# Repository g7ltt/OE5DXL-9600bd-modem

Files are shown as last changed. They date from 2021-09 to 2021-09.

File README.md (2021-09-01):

# OE5DXL-9600bd-modem

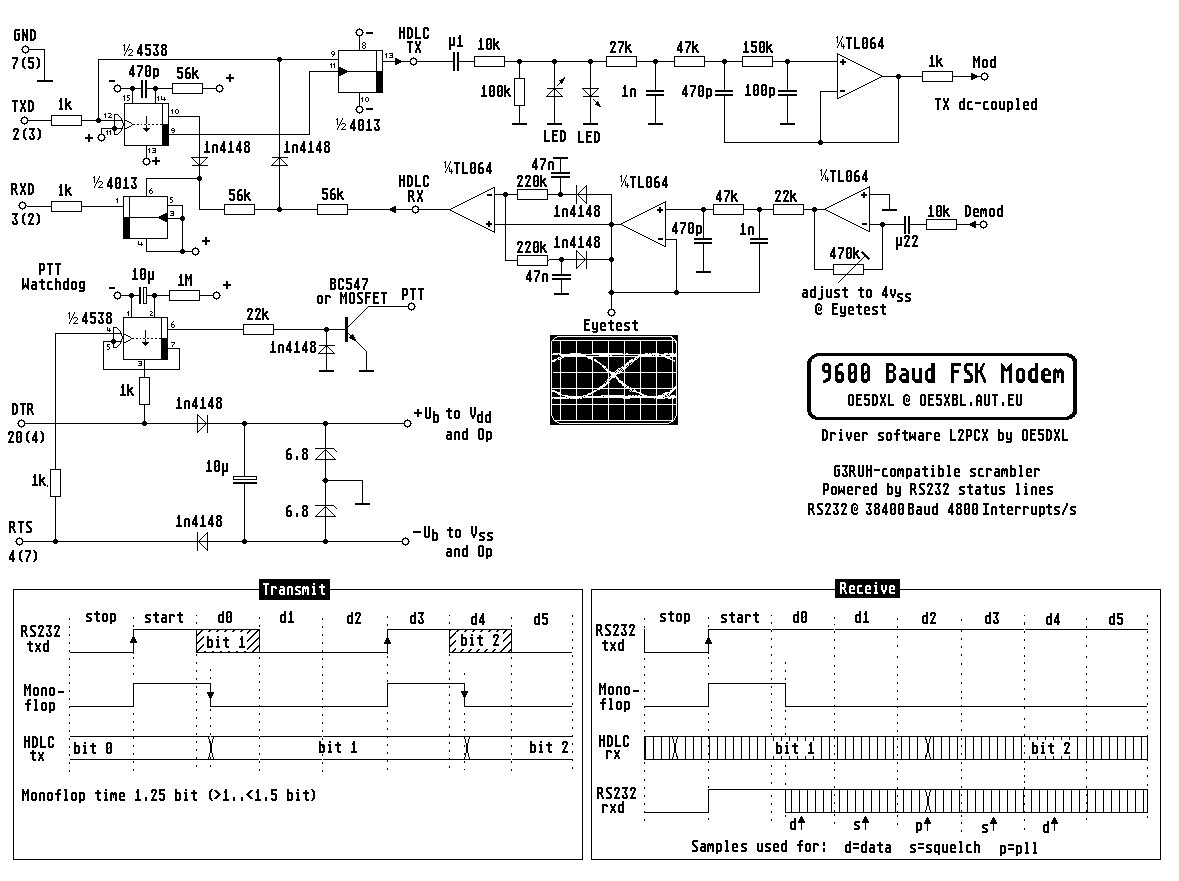
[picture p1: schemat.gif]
diagram


This modem has a very comfortable 9600bps operating speed with a suitable radio. 4 separate drivers have been written for the modem, but there is no driver in the Flexnet system .

 L2PCX.EXE Terminal Driver (Single modem) [MS-DOS]

 L2PCX4.EXE Terminal Driver (4 modems) [MS-DOS]

 ax25lib5.tgz JNOS Driver [Linux]

 agwdxl.vxd AGW Driver (Windows 9x, ME, XP)

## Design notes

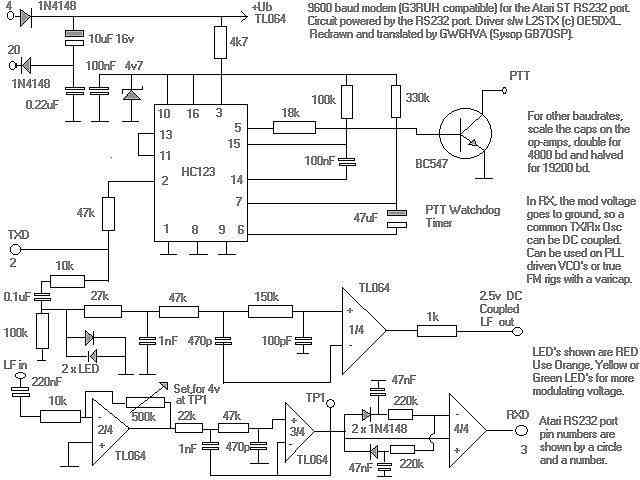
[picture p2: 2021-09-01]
l2stx.jpg

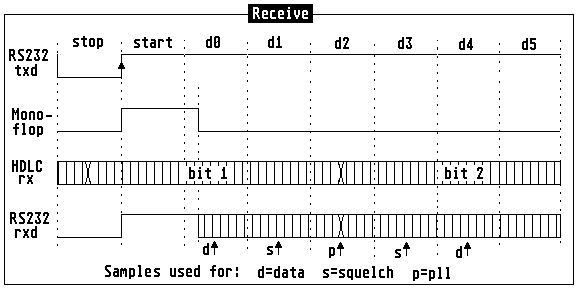
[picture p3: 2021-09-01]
recei.jpg

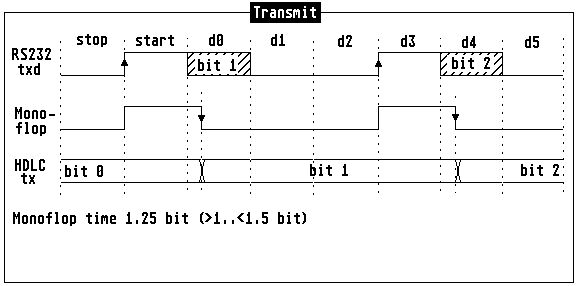
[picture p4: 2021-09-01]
trans.jpg

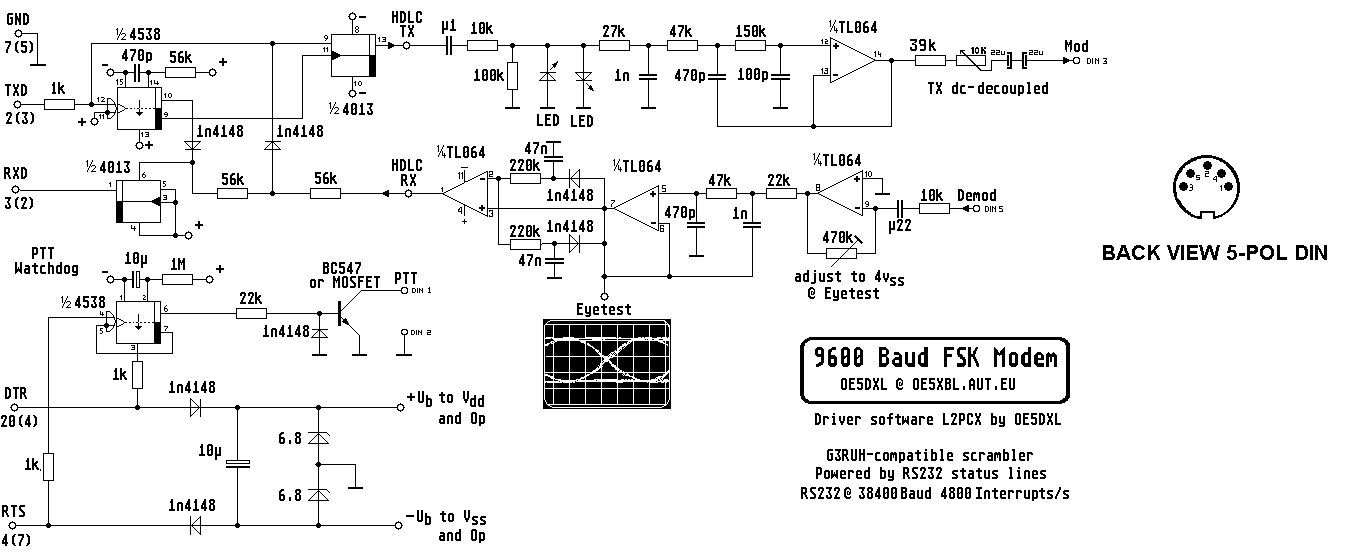
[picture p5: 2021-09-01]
oe5dxl.gif

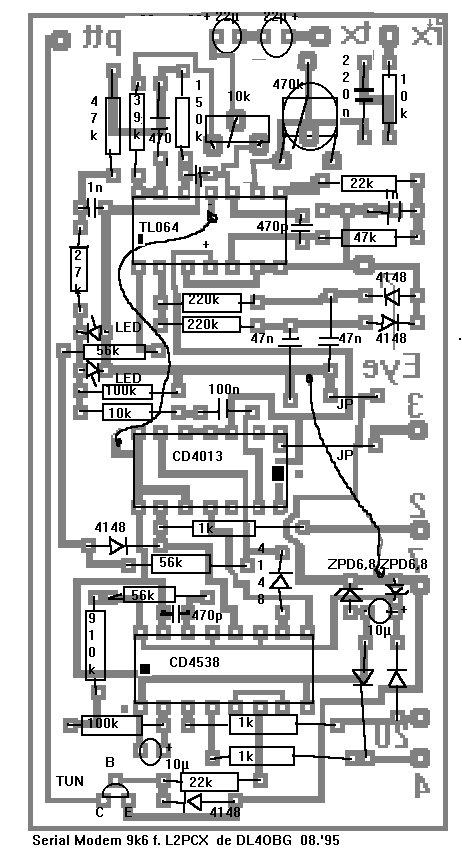
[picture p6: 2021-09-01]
pcb.gif

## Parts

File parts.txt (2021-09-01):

Exported from OE5DXL-9600.sch at 4/11/14 12:07 PM

Part     Value          Device            Package      Library        Sheet

C1       470pF          C-US025-025X050   C025-025X050 rcl            1
C2       1uF            C-US025-025X050   C025-025X050 rcl            1
C3       1nF            C-US025-025X050   C025-025X050 rcl            1
C4       470pF          C-US025-025X050   C025-025X050 rcl            1
C5       100pF          C-US025-025X050   C025-025X050 rcl            1
C6       47n            C-US025-025X050   C025-025X050 rcl            1
C7       47n            C-US025-025X050   C025-025X050 rcl            1
C8       470pF          C-US025-025X050   C025-025X050 rcl            1
C9       1nF            C-US025-025X050   C025-025X050 rcl            1
C10      22uF           C-US025-025X050   C025-025X050 rcl            1
C11      10uF           CPOL-USE2,5-6E    E2,5-6E      rcl            1
C12      10uF           CPOL-USE2,5-6E    E2,5-6E      rcl            1
D1       1N4148DO35-7   1N4148DO35-7      DO35-7       diode          1
D2       1N4148DO35-7   1N4148DO35-7      DO35-7       diode          1
D3       1N4148DO35-7   1N4148DO35-7      DO35-7       diode          1
D4       1N4148DO35-7   1N4148DO35-7      DO35-7       diode          1
D5       1N4148DO35-7   1N4148DO35-7      DO35-7       diode          1
D6       1N4148DO35-7   1N4148DO35-7      DO35-7       diode          1
D7       1N4148DO35-7   1N4148DO35-7      DO35-7       diode          1
D8       6v8            ZENER-DIODEDO34-7 DO34Z7       diode          1
D9       6v8            ZENER-DIODEDO34-7 DO34Z7       diode          1
EYE      TPPAD1-13      TPPAD1-13         P1-13        testpad        1
IC1      TL084P         TL084P            DIL14        linear         1
IC2      4013N          4013N             DIL14        40xx           1
IC3      4538N          4538N             DIL16        45xx           1
LED1                    LED3MM            LED3MM       led            1
LED2                    LED3MM            LED3MM       led            1
PC                      F09D              F09D         con-subd       1
Q1       2N3904         2N3904            TO92         transistor-npn 1
R1       1K             R-US_0207/2V      0207/2V      rcl            1
R2       56K            R-US_0207/2V      0207/2V      rcl            1
R3       56K            R-US_0207/2V      0207/2V      rcl            1
R4       56K            R-US_0207/2V      0207/2V      rcl            1
R5       1K             R-US_0207/2V      0207/2V      rcl            1
R6       1K             R-US_0207/2V      0207/2V      rcl            1
R7       10K            R-US_0207/2V      0207/2V      rcl            1
R8       100K           R-US_0207/2V      0207/2V      rcl            1
R9       27K            R-US_0207/2V      0207/2V      rcl            1
R10      47K            R-US_0207/2V      0207/2V      rcl            1
R11      47K            R-US_0207/2V      0207/2V      rcl            1
R12      220K           R-US_0207/2V      0207/2V      rcl            1
R13      220K           R-US_0207/2V      0207/2V      rcl            1
R14      47K            R-US_0207/2V      0207/2V      rcl            1
R15      22K            R-US_0207/2V      0207/2V      rcl            1
R16      470K           TRIM_US-CA6V      CA6V         pot            1
R17      10K            R-US_0207/2V      0207/2V      rcl            1
R18      1M             R-US_0207/2V      0207/2V      rcl            1
R19      1K             R-US_0207/2V      0207/2V      rcl            1
R20      1K             R-US_0207/2V      0207/2V      rcl            1
R21      22K            R-US_0207/2V      0207/2V      rcl            1
RADIO                   M09D              M09D         con-subd       1

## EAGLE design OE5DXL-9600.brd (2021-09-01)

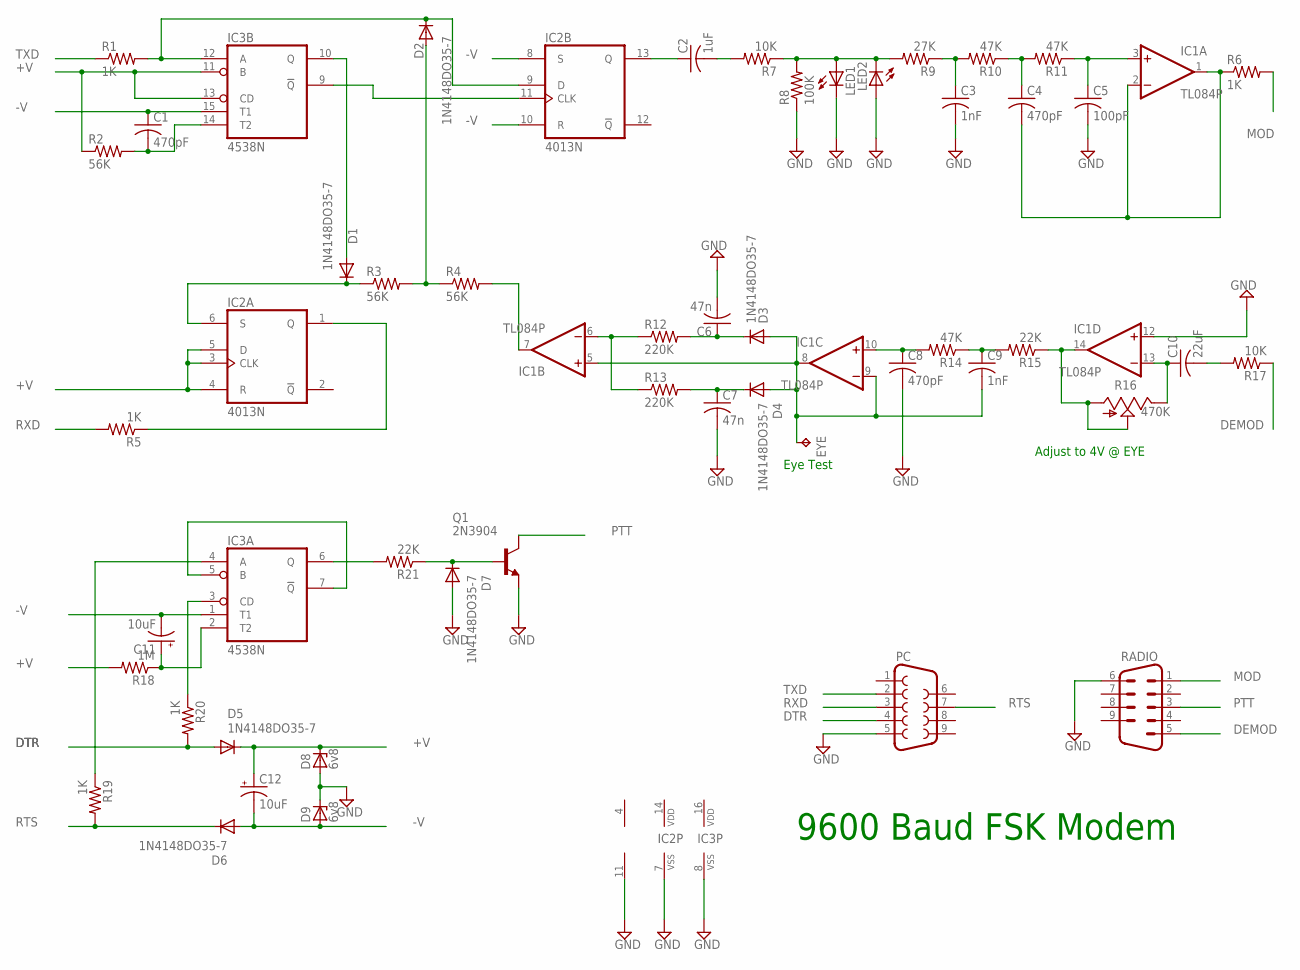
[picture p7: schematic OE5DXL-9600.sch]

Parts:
C1, C4, C8: 470pF; C025-025X050
C2: 1uF; C025-025X050
C3, C9: 1nF; C025-025X050
C5: 100pF; C025-025X050
C6, C7: 47n; C025-025X050
C10: 22uF; C025-025X050
C11, C12: 10uF; E2,5-6E
D1, D2, D3, D4, D5, D6, D7: 1N4148DO35-7; DO35-7
D8, D9: 6v8; DO34Z7
EYE: TPPAD1-13; P1-13
IC1: TL084P; DIL14
IC2: 4013N; DIL14
IC3: 4538N; DIL16
LED1, LED2: LED3MM
PC: F09D
Q1: 2N3904; TO92
R1, R5, R6, R19, R20: 1K; 0207/2V
R2, R3, R4: 56K; 0207/2V
R7, R17: 10K; 0207/2V
R8: 100K; 0207/2V
R9: 27K; 0207/2V
R10, R11, R14: 47K; 0207/2V
R12, R13: 220K; 0207/2V
R15, R21: 22K; 0207/2V
R16: 470K; CA6V
R18: 1M; 0207/2V
RADIO: M09D

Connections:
+V: C12.+, D5.C, D8.C, IC2.3 (CLK), IC2.4 (R), IC2.5 (D), IC3.11 (B), IC3.13 (CD), R2.1, R18.2
-V: C1.1, C11.-, C12.-, D6.A, D9.A, IC2.8 (S), IC2.10 (R), IC3.1 (T1), IC3.15 (T1)
DEMOD: R17.1, RADIO.5
DTR: D5.A, PC.4, R20.2
GND: C3.2, C5.2, C6.2, C7.2, C8.2, D7.A, D8.A, D9.C, IC1.11 (V-), IC1.12 (+IN), IC2.7 (VSS), IC3.8 (VSS), LED1.K (C), LED2.A, PC.5, Q1.3 (E), R8.1, RADIO.6
MOD: R6.2, RADIO.1
unnamed: D2.C, IC2.9 (D), IC3.12 (A), R1.2
unnamed: D1.C, IC2.6 (S), R3.1
unnamed: IC2.11 (CLK), IC3.9 (!Q)
unnamed: D1.A, IC3.10 (Q)
unnamed: C1.2, IC3.14 (T2), R2.2
unnamed: D2.A, R3.2, R4.1
unnamed: IC2.1 (Q), R5.1
unnamed: IC1.7 (OUT), R4.2
unnamed: C2.1, IC2.13 (Q)
unnamed: C2.2, R7.2
unnamed: LED1.A, LED2.K (C), R7.1, R8.2, R9.2
unnamed: C3.1, R9.1, R10.2
unnamed: C4.1, R10.1, R11.2
unnamed: C5.1, IC1.3 (+IN), R11.1
unnamed: C4.2, IC1.1 (OUT), IC1.2 (-IN), R6.1
unnamed: IC1.6 (-IN), R12.1, R13.1
unnamed: C6.1, D3.C, R12.2
unnamed: C9.2, D3.A, D4.A, EYE.TP, IC1.5 (+IN), IC1.8 (OUT), IC1.9 (-IN)
unnamed: IC3.5 (B), IC3.7 (!Q)
unnamed: C7.1, D4.C, R13.2
unnamed: C8.1, IC1.10 (+IN), R14.2
unnamed: C9.1, R14.1, R15.2
unnamed: IC1.14 (OUT), R15.1, R16.A, R16.S
unnamed: IC3.4 (A), R19.1
unnamed: C10.1, IC1.13 (-IN), R16.E
unnamed: C11.+, IC3.2 (T2), R18.1
unnamed: C10.2, R17.2
unnamed: IC3.3 (CD), R20.1
unnamed: IC3.6 (Q), R21.2
unnamed: D7.C, Q1.2 (B), R21.1
PTT: Q1.1 (C), RADIO.3
RTS: D6.C, PC.7, R19.2
RXD: PC.3, R5.2
TXD: PC.2, R1.1
V+: IC1.4 (V+)
VDD: IC2.14 (VDD), IC3.16 (VDD)

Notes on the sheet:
9600 Baud FSK Modem
Adjust to 4V @ EYE
Eye Test

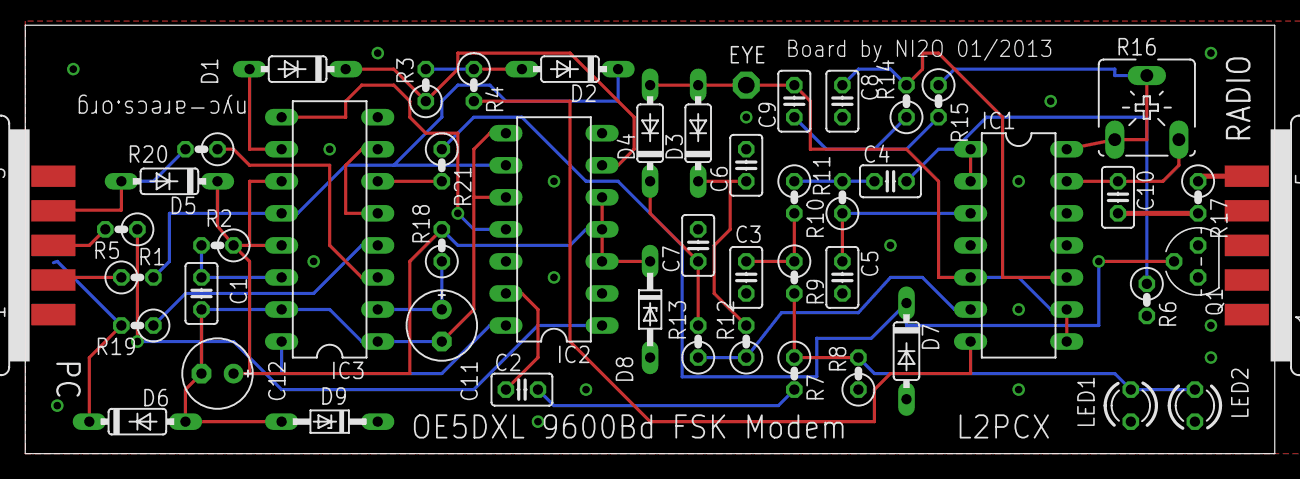
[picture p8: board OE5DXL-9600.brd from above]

Board: 2 copper layers, 99.0 x 34.0 mm, 51 parts (0 on the bottom side), 41 nets.
